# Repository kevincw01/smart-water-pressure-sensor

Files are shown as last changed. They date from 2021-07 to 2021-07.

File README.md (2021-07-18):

# smart water pressure sensor

This project pairs a pressure transducer with 2 microcontrollers which read and publish the water pressure periodically to an mqtt server.  

Why 2 microcontrollers?  Because the pressure transducers I found are all 5V-based and all the microcontrollers I found that have wifi connectivity are 3.3V-based -- annoying.  According to what I read, you cannot use a voltage divider network or a ttl-voltage converter chip for these analog sensors and get reliable readings.  

An example configuration.yaml is provided for integrating this smart sensor into home assistant.  Other smart home architectures can be supported by configuring the mqtt parameters appropriately.  

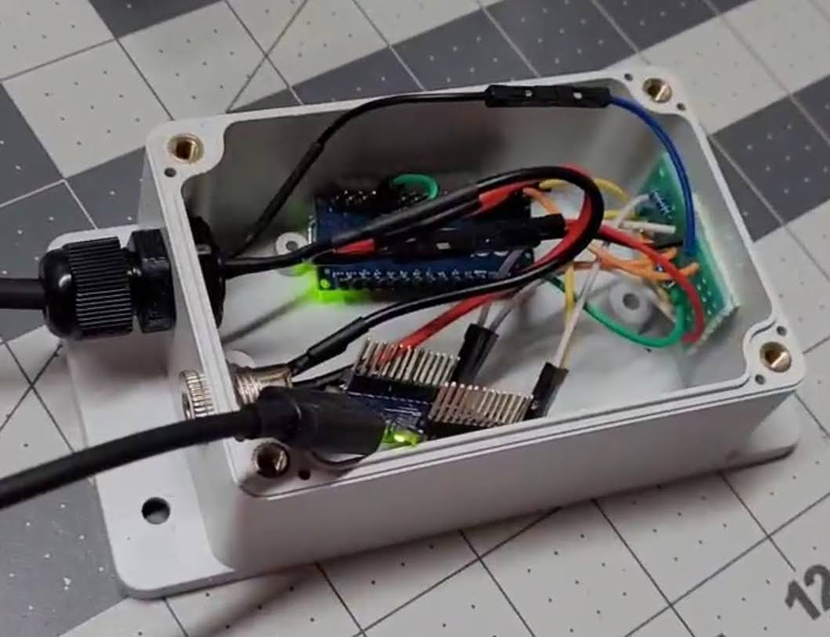
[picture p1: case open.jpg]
case open


## Installation

Review the provided wiring diagram (fritz and image provided), buy the parts, and wire it up!

You will need to buy the nano iot 33 and nano every microcontrollers, a 0.5-4.5v pressure transducer (I used [this](https://www.amazon.com/gp/product/B07Z3LRN6M/ref=ppx_yo_dt_b_asin_title_o08_s00?ie=UTF8&psc=1)) and a power supply (I just found an old 10v, 2A power supply).  

NOTE: while they should be sufficient, lower voltage and current power supplies wouldn't work for me e.g. 5v/1A.  I suspect this is due to inrush on start-up and/or my poor circuit design skills :)

Configure your wifi and MQTT credentials in the nano_33_water_sensor/credentials.h file.  Flash the arduino nano iot 33 microcontroller with the source in the nano_33_water_sensor folder.  

Flash the arduino nano every microcontroller with the source in the AnalogInput folder.

Review the configuration.yaml file and add to your home assistant installation.  You will need to add the MAC address of your nano IOT 33 to the file.  You can find this in you router's DHCP table along with the IP address.

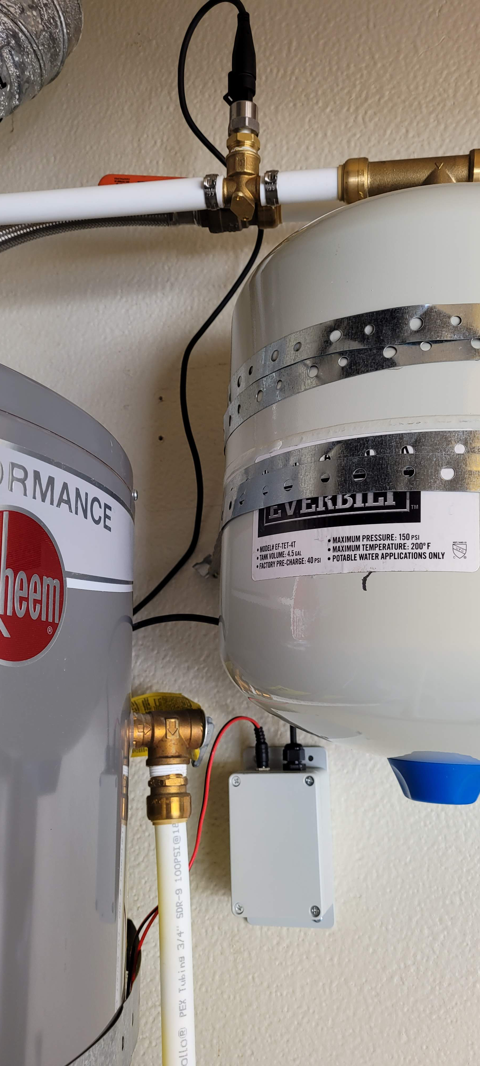
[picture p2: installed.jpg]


## Usage

Apply power to the system and confirm it is connected to wifi and the mqtt server.  Use an mqtt browser (like mqtt.fx) connected to your mqtt server (like mosquitto) to find the topic and subscribe.  View the water (or really any pressure you've connected to your sensor too) pressure publications. 

My sensor publishes to the topic:

```'arduino/Arduino-7C:9E:BD:3B:33:B0/sensor/water-pressure'```

Your topic will vary by the MAC address of your nano IOT 33.

The system will publish the pressure upon start-up and then every 5s if the pressure difference is 2+psi from the previous measurement.  If the pressure difference hasn't changed, it will still publish it every 5 minutes.  You can change all of this in the iot 33 code to your liking.

## Troubleshooting
I suggest monitoring the iot 33 serial console when you first boot it to see that it's working correctly.  You might also want to bring the iot 33 LED out to the case so that you can see status.

Every once in a while, my iot 33 doesn't connect to wifi and requires a reboot.  I'm not sure why this is.  The built-in LED will flash rapidly when this happens and I log a message to the screen.  I haven't been able to figure out how to reboot automatically yet.  Power cycling the system usually fixes this.

If the mqtt server is configured incorrectly or goes down, the iot 33 built-in LED will flash slowly 5 times, every 10s.  

There is some calibration done in the AnalogInput source code based on my experience and the sensor I have.  Feel free to adjust as required.

## Contributing
Pull requests are welcome.

## License
[GNU GPL 3.0](https://www.gnu.org/licenses/gpl-3.0.en.html)

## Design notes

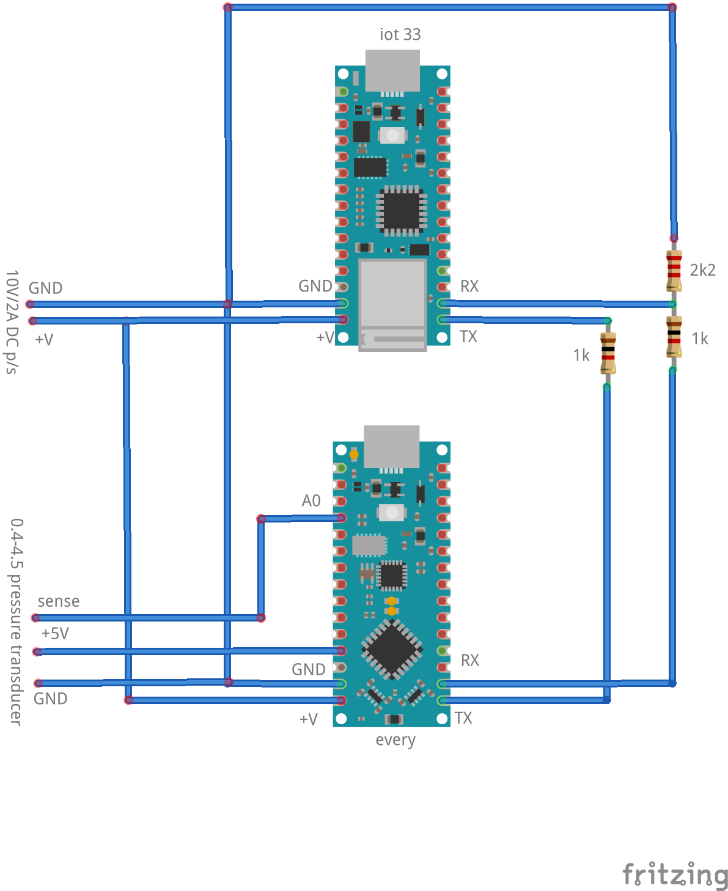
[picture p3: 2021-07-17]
circuit.png

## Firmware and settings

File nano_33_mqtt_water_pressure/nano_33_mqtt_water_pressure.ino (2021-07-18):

/****************************************************************************************************************************************************
 *  DESCRIPTION:monitors water pressure from nano every connected to 5v pressure transducer and sends to mqtt 
 *
 *  Author: Kevin Williams
 ****************************************************************************************************************************************************/

//#define DEBUG //turn on debug statements
//#define SIM_RX //simulate other microcontroller and pressure transducer w rand pressures

#ifdef DEBUG
  #define DEBUG_PRINTLN(x)  Serial.println (x)
  #define DEBUG_PRINT(x)  Serial.print (x)
#else
  #define DEBUG_PRINTLN(x)
  #define DEBUG_PRINT(x)
#endif

#include <WiFiNINA.h> 
#include <PubSubClient.h>
#include "credentials.h"
#include <stdlib.h>
#include <ArduinoJson.h>

#define LED_PIN   LED_BUILTIN

const char* ssid = networkSSID;
const char* password = networkPASSWORD;
const char* mqttServer = mqttSERVER;
const char* mqttUsername = mqttUSERNAME;
const char* mqttPassword = mqttPASSWORD;
const char* pubTopicPost = pubTopicPOST;

char pubTopic[256];       //prefix 'arduino/<clientID>'; payload[0] will have pressure value

const byte numChars = 32;
char receivedChars[numChars];

boolean newData = false;
WiFiClient wifiClient;
PubSubClient client(wifiClient);
long lastMsg = 0;
long lastPublish = 0;
char msg[50];
int value = 0;
int last_value = -10;
byte mac[6];
char MAC_addr[24];
int sensorValue = -1;

uint16_t calcCRC(char* stringData)
{
  uint16_t sum1 = 0;
  uint16_t sum2 = 0;
    
  for (int i = 0; i < strlen(stringData); i++)
  {
    sum1 = (sum1 + stringData[i]) % 255;
    sum2 = (sum2 + sum1) % 255;
  }
   return (sum2 << 8) | sum1;
}

bool checkChecksum(char* stringData, char* strArray[]) {
  bool success = false;
  char *str;
  int count = 0;
  
  if(strlen(stringData) < 5) {
    Serial.print("somthings wrong, skipping.  strlen=");
    Serial.println(strlen(stringData));  
  } else {
    while ((str = strtok_r(stringData, ",", &stringData)) != NULL)
    {
      DEBUG_PRINTLN(str);
      strArray[count] = str;
      count++;
    }
  
    char str1[16];
    strcpy(str1, strArray[0]);
    strcat(str1, ",");
    strcat(str1, strArray[1]);
    char *checkResult = str1;
    DEBUG_PRINT("split off checksum: ");
    DEBUG_PRINTLN(checkResult);
    
    uint16_t checksum = calcCRC(checkResult);
    DEBUG_PRINT("checksum=");
    DEBUG_PRINTLN(checksum);
    if(checksum == atoi(strArray[2])) {
      success=true;
      DEBUG_PRINTLN("checksum passed");
    } else
      Serial.println("checksum failed");
  }
  
  return success;
}

void setup_wifi() 
{
  delay(10);
  long last = 0;
  
  // We start by connecting to a WiFi network
  Serial.println();
  Serial.print("Connecting to ");
  Serial.println(ssid);

  WiFi.begin(ssid, password);

  while (WiFi.status() != WL_CONNECTED) 
  {
    long now = millis();
    if (now - last > 10000) 
    {
      last = now;
      Serial.println("Wifi not connecting....trying to reset");
    }
      //show status externally via led (fast blink means wifi no connected)
      digitalWrite(LED_PIN, HIGH);
      delay(150);
      Serial.print(".");
      digitalWrite(LED_PIN, LOW);
      delay(150);
      NVIC_SystemReset(); 
    
  }
  digitalWrite(LED_PIN, LOW);  //ensure led is off after wifi connect

  randomSeed(micros());

  WiFi.macAddress(mac);

  Serial.println("");
  Serial.println("WiFi connected");
  Serial.print("IP address: ");
  Serial.println(WiFi.localIP());
  Serial.print("MAC: ");
  sprintf(MAC_addr,"%02X:%02X:%02X:%02X:%02X:%02X",mac[5],mac[4],mac[3],mac[2],mac[1],mac[0]);
  Serial.println(MAC_addr);
}

void callback(char* topic, byte* payload, unsigned int length) 
{
  Serial.print("Message arrived [");
  Serial.print(topic);
  Serial.print("] ");
  for (int i = 0; i < length; i++) 
  {
    Serial.print((char)payload[i]);
  }
  Serial.println();
}

void reconnect() 
{
  // Loop until we're reconnected
  while (!client.connected()) 
  {
    Serial.print("Attempting MQTT connection...");
    char clientId[25] = "Arduino-";
    char prefix[] = "arduino/";
    strcat(clientId,MAC_addr);
    strcpy(pubTopic,prefix);
    strcat(pubTopic,clientId);
    strcat(pubTopic,pubTopicPost);
    
    // Attempt to connect
    if (client.connect(clientId, mqttUsername, mqttPassword))
    {
      Serial.print("connected w clientId=");
      Serial.println(clientId);
      // ... and resubscribe
      //client.subscribe(subTopic);
    } else 
    {
      Serial.print("failed, rc=");
      Serial.print(client.state());
      Serial.println(" try again in 5 seconds");
      
      //show status externally via led (slow blink means mqtt not connected)
      for(int i=0;i<5;i++) {  
        digitalWrite(LED_BUILTIN, HIGH);   // turn the LED on (HIGH is the voltage level)
        delay(500);                       // wait for a second
        digitalWrite(LED_BUILTIN, LOW);    // turn the LED off by making the voltage LOW
        delay(500);
      }
    }
  }
}

void recvWithStartEndMarkers() {
    static boolean recvInProgress = false;
    static byte ndx = 0;
    char startMarker = '<';
    char endMarker = '>';
    char rc;
 
    while (Serial1.available() > 0 && newData == false) {
        rc = Serial1.read();

        if (recvInProgress == true) {
            if (rc != endMarker) {
                receivedChars[ndx] = rc;
                ndx++;
                if (ndx >= numChars) {
                    ndx = numChars - 1;
                }
            }
            else {
                receivedChars[ndx] = '\0'; // terminate the string
                recvInProgress = false;
                ndx = 0;
                newData = true;
            }
        }

        else if (rc == startMarker) {
            recvInProgress = true;
        }
    }
}

void showNewData() {
    if (newData == true) {
        DEBUG_PRINT("This just in ... ");
        DEBUG_PRINTLN(receivedChars);
        newData = false;
    }
}

void setup() 
{
  pinMode(LED_PIN, OUTPUT);     
  Serial.begin(115200);
  Serial1.begin(9600); 
  setup_wifi();
  client.setServer(mqttServer, 1883);
  client.setCallback(callback);
}

void publish_mqtt(int v, char* v_s, int l) {
  
  Serial.println(v_s);
  Serial.print("on topic: ");
  Serial.print(pubTopic);
  Serial.print(" at time= ");
  Serial.println(l);

  StaticJsonDocument<200> doc;
  char jsonStr[128];

  doc["pressure"] = v_s;
  doc["wifi"] = WiFi.RSSI();

  serializeJson(doc, jsonStr);
  client.publish(pubTopic,jsonStr); 
}

void loop() 
{
  char value_s[128];
  
  if (!client.connected()) 
  {
    reconnect();
  }
  client.loop();

  long now = millis();
  if (now - lastMsg > 5000) 
  {
    lastMsg = now;

    #ifdef SIM_RX
      newData = true; //debug
    #else
      recvWithStartEndMarkers();
    #endif
            
    if (newData == true) {
      DEBUG_PRINTLN(receivedChars);
      newData = false;

      char* b = receivedChars;

      char* strArray[3];
      
      #ifdef SIM_RX
        if(1) {
          value = rand() % 100 ; 
      #else
        if(checkChecksum(b, strArray)) {
          //checksum passed for data rx from serial board
          value = atoi(strArray[1]);
      #endif   
        
        itoa(value,value_s,10);
    
        DEBUG_PRINT("rx pressure: ");
        DEBUG_PRINTLN(value_s);

        //only publish every 5 minutes or if pressure has changed by 2 psi or more
        if(abs(last_value - value) > 1) {           
          //pressure differnt by 2+ psi, publish
          lastPublish = now;  //record last time we published
          
          publish_mqtt(value,value_s,lastPublish); 
        } else {
          //publsh even if not new every 5 minutes
          if(now - lastPublish > 300000) {
            //unique value read, publish
            lastPublish = now;  //record last time we published

            Serial.print("publishing: ");
            publish_mqtt(value,value_s,lastPublish); 
          } else {
            Serial.println("not publishing bc not 2+psi different");
          }
        }
        last_value = value;
      }else {
        Serial.println("checksum failed, discarding");
      }

      memset(receivedChars, 0, 32);
    } else
      Serial.println("Error: pressure transducer microcontroller not functioning");
  }
}

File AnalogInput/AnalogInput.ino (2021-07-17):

int sensorPin = A0;    // select the input pin for the sensor
int sensorValue = 0;  // variable to store the value coming from the sensor
float voltage = 0;
int psi = 0;
const int LO_PSI = 0;
const int HI_PSI = 200;
const float LO_VOLTS = 0.5;
const float HI_VOLTS = 4.5;
const float CAL = 1.10;
int readCount = 0;

void setup() {
  Serial.begin(115200);

  Serial1.begin(9600);
}

void writeString(String stringData) { // Used to serially push out a String with Serial.write()

  for (int i = 0; i < stringData.length(); i++)
  {
    Serial1.write(stringData[i]);   // Push each char 1 by 1 on each loop pass
  }
}

uint16_t calcCRC(String stringData)
{
  uint16_t sum1 = 0;
  uint16_t sum2 = 0;
    
  for (int i = 0; i < stringData.length(); i++)
  {
    sum1 = (sum1 + stringData[i]) % 255;
    sum2 = (sum2 + sum1) % 255;
  }
   return (sum2 << 8) | sum1;
}

void loop() {
  // read the value from the sensor:
  sensorValue = analogRead(sensorPin);
  if(readCount < 2) {
    //Serial.println("discarding first 2 reads upon startup");
    readCount++;
  }else {
    sensorValue *= CAL;
    voltage = sensorValue * (4.5/1023.0);
    psi = (HI_PSI - LO_PSI) * (voltage - LO_VOLTS) / 4 + LO_PSI;

    Serial.print("read pressure as: ");
    Serial.println(psi);
  
    Serial1.flush();
    //Serial1.write(psi); 
    String s = "PSI,";
    s += psi;
  
    uint16_t crc = calcCRC(s);
    Serial.print("calculated crc=");
    Serial.println(crc); 
    s+=",";
    s+=crc;
  
    String f = "<";
    f +=s;
    f +=">";
    
    Serial.print("sending this string: ");
    Serial.println(f);
    writeString(f);
  }
    
  delay(5000);
}
